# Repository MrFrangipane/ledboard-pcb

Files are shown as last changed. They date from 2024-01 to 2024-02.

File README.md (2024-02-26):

# LED Board - PCB

v1 January 2024

This project works with
- [LED Board - Firmware minimal](https://github.com/MrFrangipane/ledboard-firmware-minimal)
- [LED Board - Desktop minimal](https://github.com/MrFrangipane/ledboard-desktop-minimal)
- [LED Board - Firmware full](https://github.com/MrFrangipane/ledboard-firmware-full)
- [LED Board - Desktop full](https://github.com/MrFrangipane/ledboard-desktop-full)

## Main board

ArtNet to LED strips (x8 RS485 transmitters)

- Raspberry Pi Pico

- ENC28J60 SPI module

- Front panel for screen, rotary encoder, push button

## Receiver  (x8)

RS485 to LED strip

## Schematics

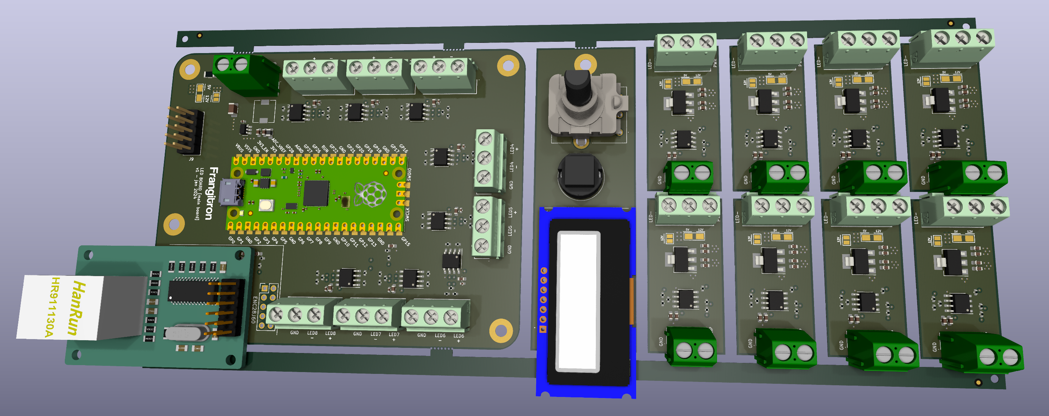
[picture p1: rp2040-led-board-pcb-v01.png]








## Gerbers

- Edge Cuts



- F Cu



- In1 Cu



- In2 Cu



- B Cu



- F Silkscreen



- B Silkscreen



- F Paste



- B Paste



- F Mask



- B Mask



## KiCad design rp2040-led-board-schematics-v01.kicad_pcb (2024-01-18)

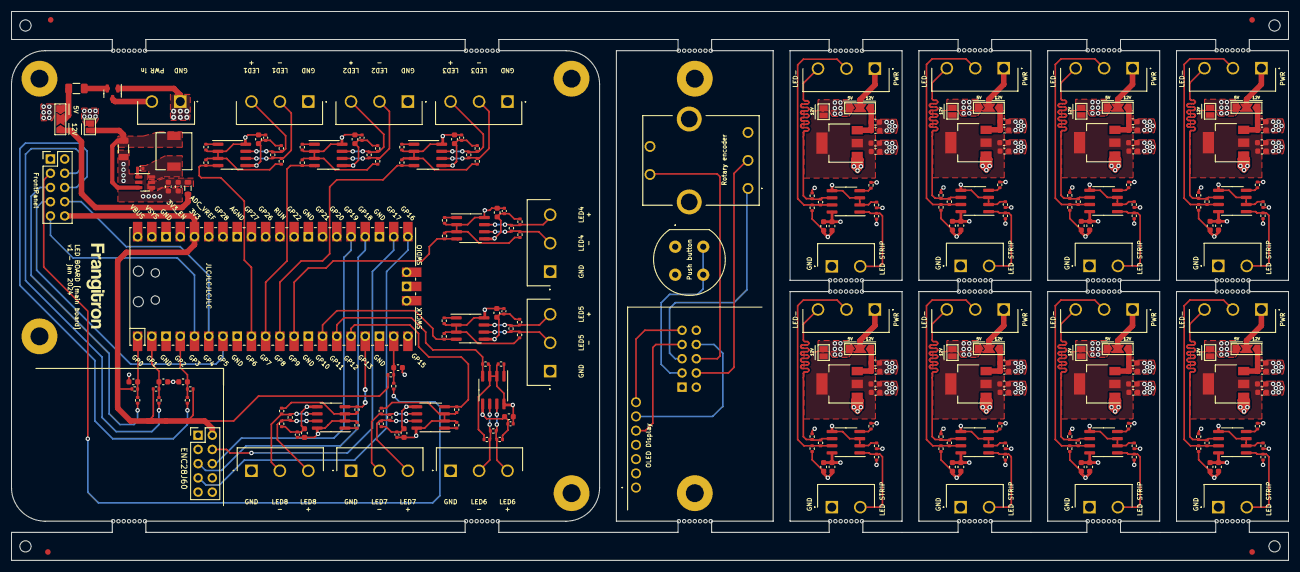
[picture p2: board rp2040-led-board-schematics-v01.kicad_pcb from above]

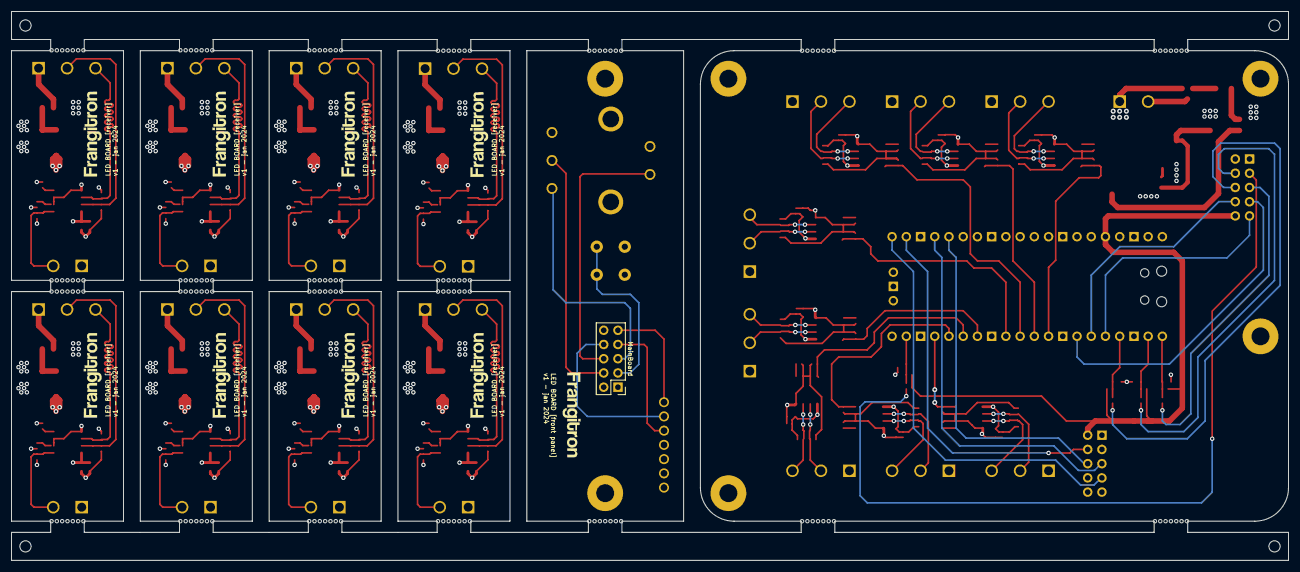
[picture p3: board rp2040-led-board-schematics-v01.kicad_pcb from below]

Board: 4 copper layers, 228.0 x 98.0 mm, 293 parts (10 on the bottom side), 139 nets.

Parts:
C1, C2, C3, C10, C12, C13, C14, C15, C19, C21, C24, C25, C29, C30, C31, C32, C38, C39, C40, C41, C47, C50, C52, C53: 10uF; C_0603_1608Metric
C4, C7, C8, C18, C28, C43, C44, C46: 10uF; C_0402_1005Metric
C5, C6, C9, C17, C20, C22, C23, C26, C27, C33, C34, C35, C36, C37, C42, C45, C48, C49, C51, C54, C55, C56, C57, C58, C59, C60, C61, C62, C63, C64, C65, C66, C67, C68, C69, C70, C71: 100nF; C_0603_1608Metric
C11: 1uF; C_0603_1608Metric
C72: 100nF; C_0402_1005Metric
C74: 10uF; C_1206_3216Metric
DS1: NHD-0216AW-IB3; NewHaven-OLED-NHD-0216AW-IB3
F1: 1A; Fuse_1206_3216Metric
FB2: 600 @ 600Mhz; L_0805_2012Metric
FM1, FM2, FM3, FM4: Fiducial; Fiducial_1mm_Mask2mm
H1, H2, H32, H33: MountingHole; MountingHole_2mm
H3, H4, H5, H6, H7, H8, H9, H14, H15, H16, H17, H18, H19, H20, H21, H25, H26, H27, H28, H29, H30, H31: mouse-bites-1x07-jlc
H10, H11, H12, H22, H23, H24: MountingHole_Pad; MountingHole_3.2mm_M3_Pad
H13, H34, H35, H36, H37, H38, H39, H40, H41, H42: frangitron_logo_16mm
J1, J2, J3, J4, J15, J16, J17, J18: ReceiverRS485; ScrewTerminal_01x03_5.08_Amphenol
J5: PWR_IN; ScrewTerminal_01x02_5.08_Amphenol
J6, J7, J8, J10, J19, J20, J21, J22: Terminal; ScrewTerminal_01x03_5.08_Amphenol
J9: FrontPanel; PinHeader_2x05_P2.54mm_Vertical
J11, J12, J13, J14, J23, J24, J25, J26: ReceiverData; ScrewTerminal_01x02_5.08_Amphenol
J27: MainBoard; PinHeader_2x05_P2.54mm_Vertical
JP1, JP2, JP3, JP4, JP10, JP11, JP12, JP13, JP14: 1-2 12V; SolderJumper-3_P2.0mm_Open_TrianglePad1.0x1.5mm_NumberLabels
JP5, JP6, JP7, JP8, JP9, JP15, JP16, JP17, JP18: 12V; SolderJumper-2_P1.3mm_Open_Pad1.0x1.5mm
L1: 5.6mH; L_6.3x6.3_H3
Q1: AO3401A; SOT-23
R1, R2, R5, R6, R11, R12, R17, R19, R21, R23, R24, R28, R29, R32, R33, R36, R37, R40, R41, R42, R45, R46, R50, R51, R62, R65, R67, R69, R76, R77, R81, R82, R86, R87, R91, R92, R93, R94, R95, R96: 10K; R_0402_1005Metric
R3, R10, R13, R27, R31, R34, R39, R44, R48, R60, R64, R72, R75, R78, R84, R90: 120; R_0402_1005Metric
R4, R7, R8, R9, R14, R15, R16, R18, R20, R22, R25, R26, R30, R35, R38, R43, R47, R49, R61, R63, R66, R68, R70, R71, R73, R74, R79, R80, R83, R85, R88, R89: 20K; R_0402_1005Metric
R52, R53, R54, R56: 10k; R_0402_1005Metric
R55, R57, R58, R59: 1k; R_0402_1005Metric
SW1: PEC16; PEC164120FS0012
SW2: Button; C&K_PushButtonSwitch_SPST_D6C90F2LFS
U2: LMR50410Y5FQDBVRQ1; SOT-23-6
U6, U7, U8, U9, U10, U11, U12, U13, U15, U16, U21, U22, U23, U24, U25, U26: MAX485EE; SOIC-8_3.9x4.9mm_P1.27mm
U14: Pico; RPi_Pico_SMD_TH
U17, U29, U30, U31, U32, U33, U34, U35: AMS1117-5.0; SOT-223-3_TabPin2
U27: ENC28J60; ENC28J60-SPI-Ethernet-Module

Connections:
+3V3: J9.10, R52.1, R53.1, R54.1, R56.1, U14.36 (3V3), U27.9 (VCC)
+5V: C4.1, C5.1, C6.1, C7.1, C8.1, C9.1, C17.1, C18.1, C27.1, C28.1, C37.1, C42.1, C43.1, C44.1, C45.1, C46.1, JP5.2 (B), JP10.3 (B), R1.1, R2.1, R4.1, R5.1, R6.1, R9.1, R11.1, R12.1, R15.1, R24.1, R42.1, R43.1, R45.1, R46.1, R47.1, R50.1, R51.1, R61.1, R62.1, R63.1, R65.1, R67.1, R69.1, R71.1, U6.2 (~RE), U6.3 (DE), U6.8 (VCC), U7.2 (~RE), U7.3 (DE), U7.8 (VCC), U8.2 (~RE), U8.3 (DE), U8.8 (VCC), U13.2 (~RE), U13.3 (DE), U13.8 (VCC), U14.39 (VSYS), U15.2 (~RE), U15.3 (DE), U15.8 (VCC), U16.2 (~RE), U16.3 (DE), U16.8 (VCC), U21.2 (~RE), U21.3 (DE), U21.8 (VCC), U22.2 (~RE), U22.3 (DE), U22.8 (VCC)
+12V: FB2.1, JP10.1 (A)
/Buck in: C11.1, C71.1, FB2.2, U2.4 (EN), U2.5 (VIN)
/Buck out: C74.1, JP5.1 (A), L1.2, U2.3 (FB)
/CB: C72.2, U2.1 (CB)
/FP +3V3: DS1.2 (VDD_SEL), DS1.3 (VDDIO), J27.10
/FP GND: DS1.1 (GND), DS1.4 (SA0), H12.1, H24.1, J27.1, SW1.C1, SW1.E1, SW2.1, SW2.2
/LED to RS485 1/D+: J6.3, R3.1, R7.1, U6.7 (B)
/LED to RS485 1/D-: J6.2, R3.2, R4.2, U6.6 (A)
/LED to RS485 2/D+: J7.3, R8.1, R10.1, U7.7 (B)
/LED to RS485 2/D-: J7.2, R9.2, R10.2, U7.6 (A)
/LED to RS485 3/D+: J8.3, R13.1, R14.1, U8.7 (B)
/LED to RS485 3/D-: J8.2, R13.2, R15.2, U8.6 (A)
/LED to RS485 4/D+: J10.3, R25.1, R44.1, U13.7 (B)
/LED to RS485 4/D-: J10.2, R43.2, R44.2, U13.6 (A)
/LED to RS485 5/D+: J19.3, R48.1, R49.1, U15.7 (B)
/LED to RS485 5/D-: J19.2, R47.2, R48.2, U15.6 (A)
/LED to RS485 6/D+: J22.3, R70.1, R72.1, U16.7 (B)
/LED to RS485 6/D-: J22.2, R71.2, R72.2, U16.6 (A)
/LED to RS485 7/D+: J21.3, R64.1, R68.1, U22.7 (B)
/LED to RS485 7/D-: J21.2, R63.2, R64.2, U22.6 (A)
/LED to RS485 8/D+: J20.3, R60.1, R66.1, U21.7 (B)
/LED to RS485 8/D-: J20.2, R60.2, R61.2, U21.6 (A)
/Receiver 1/5V: C47.1, C48.1, JP11.3 (B), JP15.1 (A), R73.1, R76.1, R77.1, R93.1, U23.8 (VCC)
/Receiver 1/12V: C29.1, C55.1, JP11.1 (A), U17.3 (VI)
/Receiver 1/D+: J15.2, R74.1, R75.1, U23.7 (B)
/Receiver 1/D-: J15.3, R73.2, R75.2, U23.6 (A)
/Receiver 1/DATA: J23.2, R93.2, U23.1 (RO)
/Receiver 1/GND: C29.2, C38.2, C47.2, C48.2, C55.2, C63.2, J23.1, R74.2, R77.2, U17.1 (GND), U23.2 (~RE), U23.3 (DE), U23.5 (GND)
/Receiver 1/LDO OUT: C38.1, C63.1, JP15.2 (B), U17.2 (VO)
/Receiver 1/PWR IN: J15.1, JP11.2 (C)
/Receiver 2/5V: C19.1, C20.1, JP1.3 (B), JP6.1 (A), R16.1, R17.1, R28.1, R29.1, U9.8 (VCC)
/Receiver 2/12V: C10.1, C56.1, JP1.1 (A), U29.3 (VI)
/Receiver 2/D+: J1.2, R26.1, R27.1, U9.7 (B)
/Receiver 2/D-: J1.3, R16.2, R27.2, U9.6 (A)
/Receiver 2/DATA: J11.2, R29.2, U9.1 (RO)
/Receiver 2/GND: C10.2, C12.2, C19.2, C20.2, C56.2, C64.2, J11.1, R26.2, R28.2, U9.2 (~RE), U9.3 (DE), U9.5 (GND), U29.1 (GND)
/Receiver 2/LDO OUT: C12.1, C64.1, JP6.2 (B), U29.2 (VO)
/Receiver 2/PWR IN: J1.1, JP1.2 (C)
/Receiver 3/5V: C49.1, C50.1, JP12.3 (B), JP16.1 (A), R79.1, R81.1, R82.1, R94.1, U24.8 (VCC)
/Receiver 3/12V: C30.1, C57.1, JP12.1 (A), U30.3 (VI)
/Receiver 3/D+: J16.2, R78.1, R80.1, U24.7 (B)
/Receiver 3/D-: J16.3, R78.2, R79.2, U24.6 (A)
/Receiver 3/DATA: J24.2, R94.2, U24.1 (RO)
/Receiver 3/GND: C30.2, C39.2, C49.2, C50.2, C57.2, C65.2, J24.1, R80.2, R81.2, U24.2 (~RE), U24.3 (DE), U24.5 (GND), U30.1 (GND)
/Receiver 3/LDO OUT: C39.1, C65.1, JP16.2 (B), U30.2 (VO)
/Receiver 3/PWR IN: J16.1, JP12.2 (C)
/Receiver 4/5V: C21.1, C22.1, JP2.3 (B), JP7.1 (A), R18.1, R19.1, R32.1, R33.1, U10.8 (VCC)
/Receiver 4/12V: C1.1, C58.1, JP2.1 (A), U31.3 (VI)
/Receiver 4/D+: J2.2, R30.1, R31.1, U10.7 (B)
/Receiver 4/D-: J2.3, R18.2, R31.2, U10.6 (A)
/Receiver 4/DATA: J12.2, R32.2, U10.1 (RO)
/Receiver 4/GND: C1.2, C13.2, C21.2, C22.2, C58.2, C66.2, J12.1, R30.2, R33.2, U10.2 (~RE), U10.3 (DE), U10.5 (GND), U31.1 (GND)
/Receiver 4/LDO OUT: C13.1, C66.1, JP7.2 (B), U31.2 (VO)
/Receiver 4/PWR IN: J2.1, JP2.2 (C)
/Receiver 5/5V: C51.1, C52.1, JP13.3 (B), JP17.1 (A), R83.1, R86.1, R87.1, R95.1, U25.8 (VCC)
/Receiver 5/12V: C31.1, C59.1, JP13.1 (A), U32.3 (VI)
/Receiver 5/D+: J17.2, R84.1, R85.1, U25.7 (B)
/Receiver 5/D-: J17.3, R83.2, R84.2, U25.6 (A)
/Receiver 5/DATA: J25.2, R95.2, U25.1 (RO)
/Receiver 5/GND: C31.2, C40.2, C51.2, C52.2, C59.2, C67.2, J25.1, R85.2, R86.2, U25.2 (~RE), U25.3 (DE), U25.5 (GND), U32.1 (GND)
/Receiver 5/LDO OUT: C40.1, C67.1, JP17.2 (B), U32.2 (VO)
/Receiver 5/PWR IN: J17.1, JP13.2 (C)
/Receiver 6/5V: C23.1, C24.1, JP3.3 (B), JP8.1 (A), R20.1, R21.1, R36.1, R37.1, U11.8 (VCC)
/Receiver 6/12V: C2.1, C60.1, JP3.1 (A), U33.3 (VI)
/Receiver 6/D+: J3.2, R34.1, R35.1, U11.7 (B)
/Receiver 6/D-: J3.3, R20.2, R34.2, U11.6 (A)
/Receiver 6/DATA: J13.2, R37.2, U11.1 (RO)
/Receiver 6/GND: C2.2, C14.2, C23.2, C24.2, C60.2, C68.2, J13.1, R35.2, R36.2, U11.2 (~RE), U11.3 (DE), U11.5 (GND), U33.1 (GND)
/Receiver 6/LDO OUT: C14.1, C68.1, JP8.2 (B), U33.2 (VO)
/Receiver 6/PWR IN: J3.1, JP3.2 (C)
/Receiver 7/5V: C53.1, C54.1, JP14.3 (B), JP18.1 (A), R89.1, R91.1, R92.1, R96.1, U26.8 (VCC)
/Receiver 7/12V: C32.1, C61.1, JP14.1 (A), U34.3 (VI)
/Receiver 7/D+: J18.2, R88.1, R90.1, U26.7 (B)
/Receiver 7/D-: J18.3, R89.2, R90.2, U26.6 (A)
/Receiver 7/DATA: J26.2, R96.2, U26.1 (RO)
/Receiver 7/GND: C32.2, C41.2, C53.2, C54.2, C61.2, C69.2, J26.1, R88.2, R92.2, U26.2 (~RE), U26.3 (DE), U26.5 (GND), U34.1 (GND)
/Receiver 7/LDO OUT: C41.1, C69.1, JP18.2 (B), U34.2 (VO)
/Receiver 7/PWR IN: J18.1, JP14.2 (C)
/Receiver 8/5V: C25.1, C26.1, JP4.3 (B), JP9.1 (A), R22.1, R23.1, R40.1, R41.1, U12.8 (VCC)
/Receiver 8/12V: C3.1, C62.1, JP4.1 (A), U35.3 (VI)
/Receiver 8/D+: J4.2, R38.1, R39.1, U12.7 (B)
/Receiver 8/D-: J4.3, R22.2, R39.2, U12.6 (A)
/Receiver 8/DATA: J14.2, R40.2, U12.1 (RO)
/Receiver 8/GND: C3.2, C15.2, C25.2, C26.2, C62.2, C70.2, J14.1, R38.2, R41.2, U12.2 (~RE), U12.3 (DE), U12.5 (GND), U35.1 (GND)
/Receiver 8/LDO OUT: C15.1, C70.1, JP9.2 (B), U35.2 (VO)
/Receiver 8/PWR IN: J4.1, JP4.2 (C)
/SW: C72.1, L1.1, U2.6 (SW)
FPDisplayRST: DS1.7 (~RES), J27.9
FPDisplaySCL: DS1.5 (SCL), J27.7
FPDisplaySDA: DS1.6 (SDA), J27.8
FPEncoderA: J27.5, SW1.A1
FPEncoderB: J27.4, SW1.B1
FPEncoderS: J27.6, SW1.D1
FPSwitchPush: J27.3, SW2.3 (K), SW2.4 (A)
GND: C4.2, C5.2, C6.2, C7.2, C8.2, C9.2, C11.2, C17.2, C18.2, C27.2, C28.2, C33.2, C34.2, C35.2, C36.2, C37.2, C42.2, C43.2, C44.2, C45.2, C46.2, C71.2, C74.2, H10.1, H11.1, H22.1, H23.1, J5.1, J6.1, J7.1, J8.1, J9.1, J10.1, J19.1, J20.1, J21.1, J22.1, Q1.1 (G), R7.2, R8.2, R14.2, R25.2, R49.2, R66.2, R68.2, R70.2, U2.2 (GND), U6.5 (GND), U7.5 (GND), U8.5 (GND), U13.5 (GND), U14.3 (GND), U14.8 (GND), U14.13 (GND), U14.18 (GND), U14.23 (GND), U14.28 (GND), U14.42 (GND), U15.5 (GND), U16.5 (GND), U21.5 (GND), U22.5 (GND), U27.10 (GND)
LED1 out: R1.2, U6.4 (DI), U14.9 (GPIO6)
LED2 out: R5.2, U7.4 (DI), U14.10 (GPIO7)
LED3 out: R11.2, U8.4 (DI), U14.11 (GPIO8)
LED4 out: R42.2, U13.4 (DI), U14.12 (GPIO9)
LED5 out: R46.2, U14.14 (GPIO10), U15.4 (DI)
LED6 out: R51.2, U14.15 (GPIO11), U16.4 (DI)
LED7 out: R65.2, U14.16 (GPIO12), U22.4 (DI)
LED8 out: R62.2, U14.17 (GPIO13), U21.4 (DI)
MBEncoderA: J9.5, R58.2
MBEncoderB: J9.4, R57.2
MBEncoderS: J9.6, R59.1
MBSwitchPush: J9.3, R55.2
MCUDisplayRST: J9.9, U14.5 (GPIO3)
MCUDisplaySCL: J9.7, U14.7 (GPIO5)
MCUDisplaySDA: J9.8, U14.6 (GPIO4)
MCUEncoderA: C33.1, R52.2, R58.1, U14.1 (GPIO0)
MCUEncoderB: C34.1, R53.2, R57.1, U14.2 (GPIO1)
MCUEncoderS: C35.1, R54.2, R59.2, U14.4 (GPIO2)
MCUSwitchPush: C36.1, R55.1, R56.2, U14.19 (GPIO14)
unnamed: J5.2, Q1.3 (D)
unnamed: F1.1, JP10.2 (C)
unnamed: F1.2, Q1.2 (S)
unnamed: R2.2, U6.1 (RO)
unnamed: R6.2, U7.1 (RO)
unnamed: R12.2, U8.1 (RO)
unnamed: R17.2, U9.4 (DI)
unnamed: R19.2, U10.4 (DI)
unnamed: R21.2, U11.4 (DI)
unnamed: R23.2, U12.4 (DI)
unnamed: R24.2, U13.1 (RO)
unnamed: R45.2, U15.1 (RO)
unnamed: R50.2, U16.1 (RO)
unnamed: R67.2, U21.1 (RO)
unnamed: R69.2, U22.1 (RO)
unnamed: R76.2, U23.4 (DI)
unnamed: R82.2, U24.4 (DI)
unnamed: R87.2, U25.4 (DI)
unnamed: R91.2, U26.4 (DI)
PI spi0 CSn: U14.22 (GPIO17), U27.7 (CS)
PI spi0 RX: U14.21 (GPIO16), U27.4 (SO)
PI spi0 SCK: U14.24 (GPIO18), U27.6 (SCK)
PI spi0 TX: U14.25 (GPIO19), U27.5 (SI)

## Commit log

2024-01-12 footprints ok
    [rp2040-led-board-schematics-v02.kicad_pcb, rp2040-led-board-schematics-v02.kicad_sch]
2024-01-12 start Phil's Lab tutorial
    [rp2040-led-board-schematics-v02.kicad_pcb]
2024-01-13 main board PCB done (needs checking)
    [led-to-rs485.kicad_sch, rp2040-led-board-schematics-v02.kicad_pcb, rp2040-led-board-schematics-v02.kicad_sch]
2024-01-14 fix ENC module dimensions + adapt pcb accordingly
    [rp2040-led-board-schematics-v02.kicad_pcb]
2024-01-14 1st panel test, before cloning 8 receivers
    [Receiver.kicad_sch, rp2040-led-board-schematics-v02.kicad_pcb, rp2040-led-board-schematics-v02.kicad_sch]
2024-01-14 receiver layout OK, some references fixed
    [Receiver.kicad_sch, rp2040-led-board-schematics-v02.kicad_pcb, rp2040-led-board-schematics-v02.kicad_sch]
2024-01-15 OK for first fabrication review
    [Receiver.kicad_sch, rp2040-led-board-schematics-v02.kicad_pcb, rp2040-led-board-schematics-v02.kicad_sch]
2024-01-15 unify receiver layout, reduce global heigt by 1mm for symmetry
    [rp2040-led-board-schematics-v02.kicad_pcb]
2024-01-15 panelization with only mouse bites, routing finished
    [Receiver.kicad_sch, rp2040-led-board-schematics-v02.kicad_pcb, rp2040-led-board-schematics-v02.kicad_sch]
2024-01-15 resize front panel, fix header orientation, fix receivers layouts and footprints
    [rp2040-led-board-schematics-v02.kicad_pcb, rp2040-led-board-schematics-v02.kicad_sch]
2024-01-15 Geographically reannotate
    [Receiver.kicad_sch, led-to-rs485.kicad_sch, rp2040-led-board-schematics-v02.kicad_pcb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]
2024-01-16 fix power sources, update reveivers accordingly (main board PCB not updated yet)
    [Receiver.kicad_sch, led-to-rs485.kicad_sch, rp2040-led-board-schematics-v02.kicad_pcb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]
2024-01-16 should be ready to find parts
    [Receiver.kicad_sch, rp2040-led-board-schematics-v02.kicad_pcb, rp2040-led-board-schematics-v02.kicad_sch]
2024-01-16 fix: update .svg & .png files, correct some silkscreen details
    [rp2040-led-board-schematics-v02.kicad_pcb]
2024-01-16 fix: DRC & ERC revealed designators were out of sync between schem and pcb
    [Receiver.kicad_sch, rp2040-led-board-schematics-v02.kicad_pcb, rp2040-led-board-schematics-v02.kicad_sch]
2024-01-16 JLCPCB pluging assignation done
    [rp2040-led-board-schematics-v02.kicad_pcb]
2024-01-17 order placed
    [Receiver.kicad_sch, rp2040-led-board-schematics-v02.kicad_pcb, rp2040-led-board-schematics-v02.kicad_sch]
2024-01-17 rename to v1 (to match silkscreen), improve readme and schematics layouts
    [Receiver.kicad_sch, Transmitter.kicad_sch, rp2040-led-board-schematics-v01.kicad_pcb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]
2024-01-17 add gerbers to readme
2024-01-18 remove designators from silkscreens (manufacturer considers different designs otherwise)
    [rp2040-led-board-schematics-v01.kicad_pcb]
2024-01-18 fix: remove designators from silkscreens (forgot some)
    [rp2040-led-board-schematics-v01.kicad_pcb]
